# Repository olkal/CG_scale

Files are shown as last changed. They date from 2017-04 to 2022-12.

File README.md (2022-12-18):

# F3X CG_scale
Arduino based Open Source CG scale for F3X gliders (and other model airplanes)
The scale can be used for most modern F3F/F3B gliders with slim fuselages and will calculate the CG and weight.

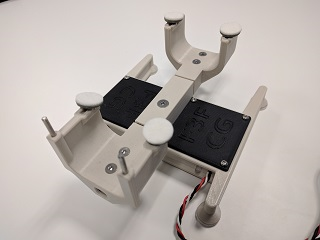
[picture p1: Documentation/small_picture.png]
CG_scale


Update 18.12.2022 1.2.2, changed to a better i2c library for the 1602 LCD

Update 05.02.2022 1.2.1, minor bug fix + optional larger LCD box bottom part

Update 01.12.2021 1.2.0, Arduino code re-write:
- New function: Serial Monitor menu/input
- New function: Calibration routine for loadcells
- New function: Calibration routine for battery voltage
- Configuration parameters in new file config.h
- Store calibration values in EEPROM
- I2C Display code changed
- Display battery voltage also for I2C display
- Optional Zero Offset button included
- Low battery warning
- Updated instructions, circuit diagram and BOM
- ++

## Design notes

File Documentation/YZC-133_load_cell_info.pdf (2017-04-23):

15V DC YZC-133 2kg Weighing Sensor Load Cell Aluminum Alloy Electronic Scale Weighing Sensor
Rated Load: 2Kg
Rated Output: 1.0 ±0.15mV/V
Zero Output: ±0.1mV/V
Cree: 0.03%F.S./30min
Input End: Red+, Black-Output End: Green+, White-Input Impedance: 1115±10% Ω Output Impedance: 1000±10% Ω
Maximum working voltage: 15V DC
Operating temperature range: -20~60°C
Total Size: 80 x 13 x 13mm/3.14 x 0.51 x 0.51"(L X W X H) Material: Aluminum Alloy
Weight: 23g

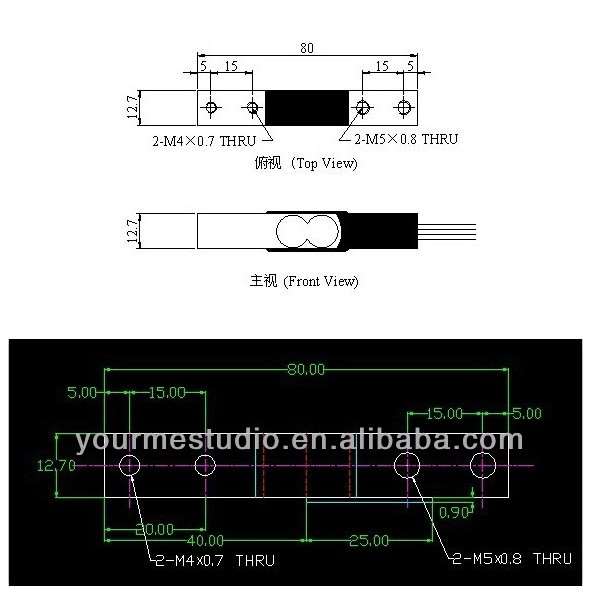
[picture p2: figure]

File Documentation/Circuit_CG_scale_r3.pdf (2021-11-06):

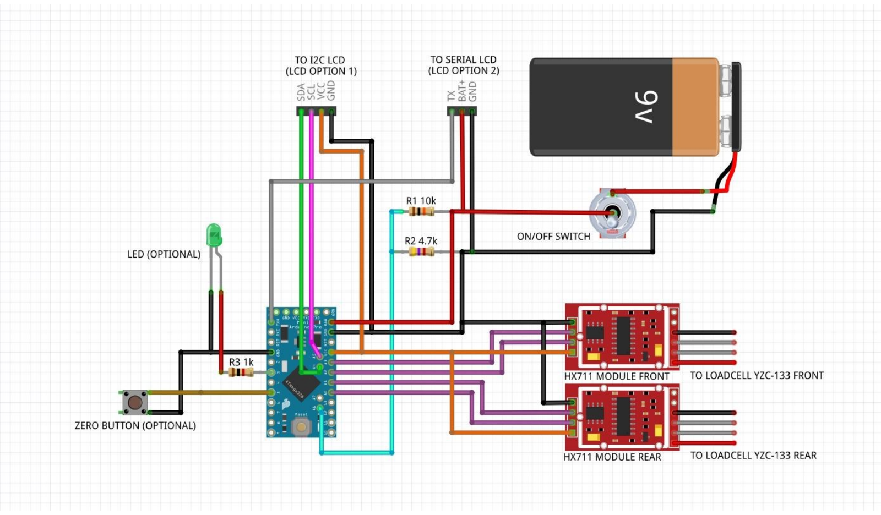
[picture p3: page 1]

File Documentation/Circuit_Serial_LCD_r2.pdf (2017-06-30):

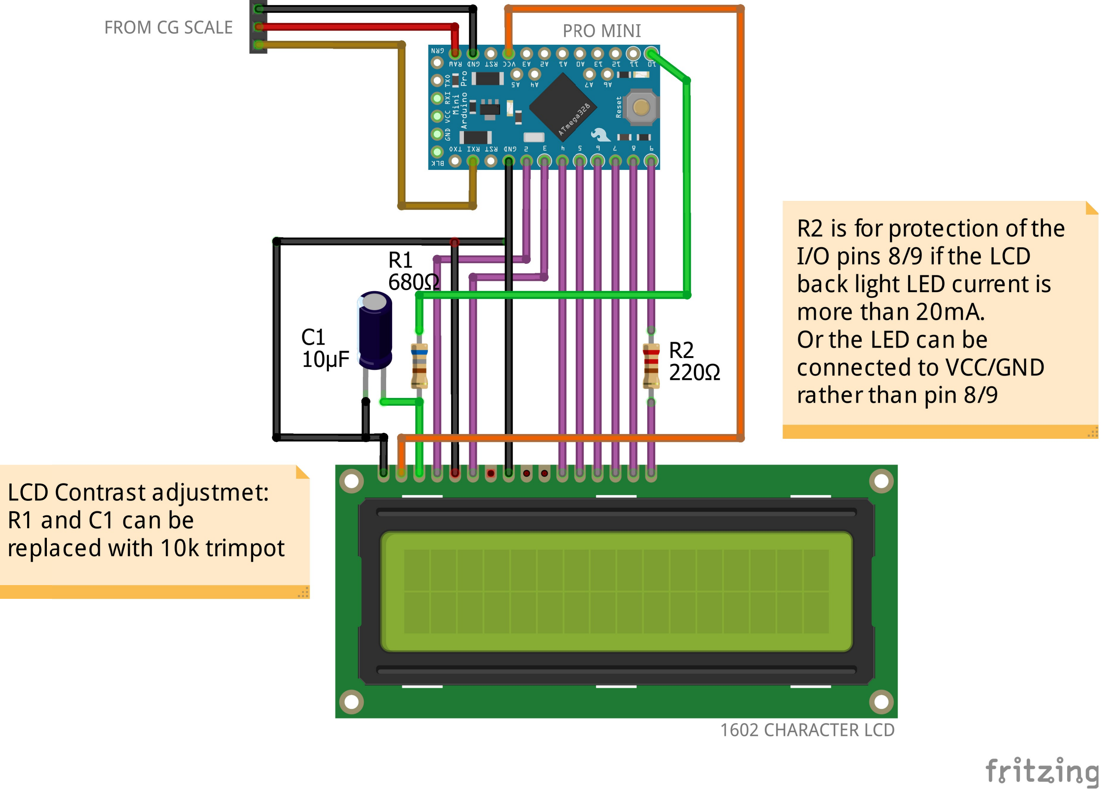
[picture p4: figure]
LCD Contrast adjustmet: R1 and C1 can be replaced with 10k trimpot

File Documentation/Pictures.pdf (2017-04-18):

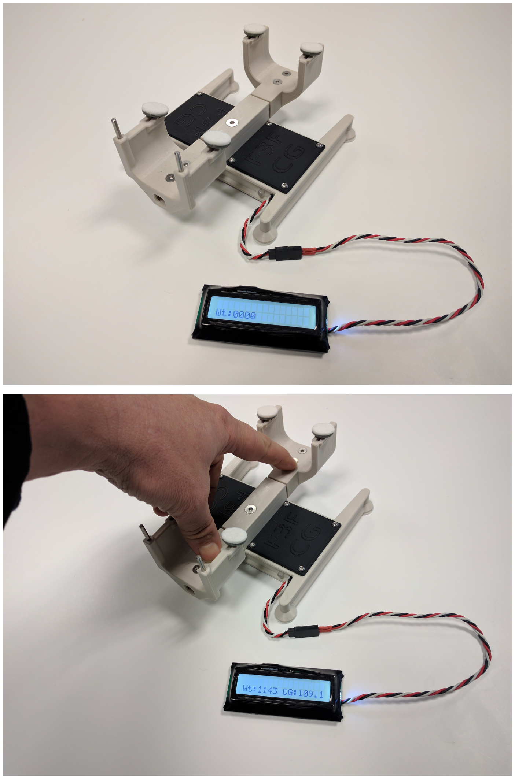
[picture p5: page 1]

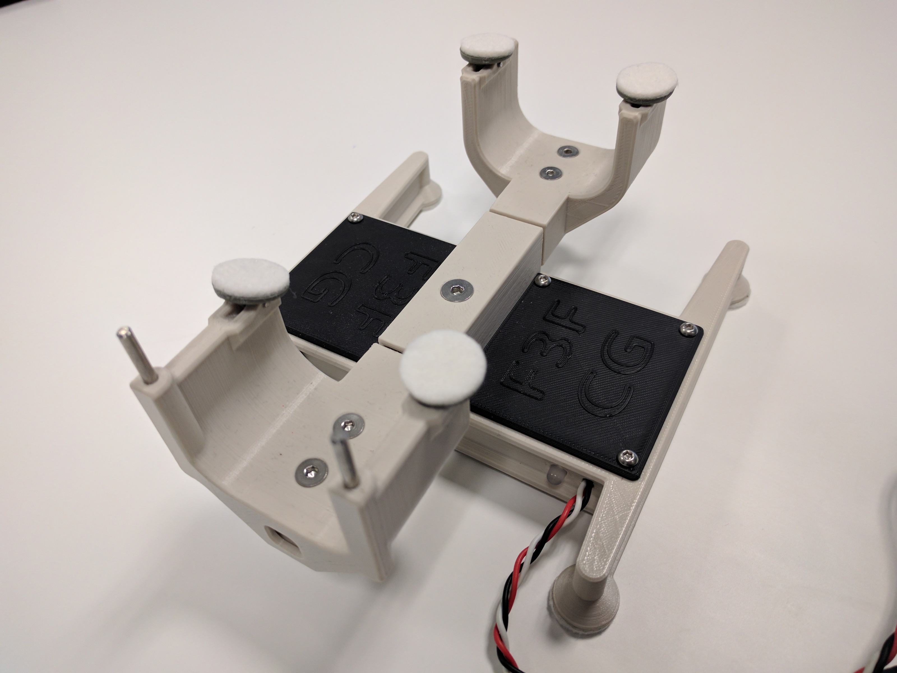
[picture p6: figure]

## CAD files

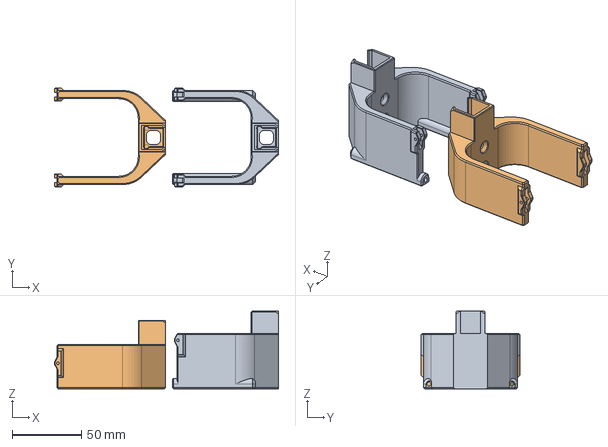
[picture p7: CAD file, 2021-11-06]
Documentation/Source files/CG_scale_parts_f5j_3dprint.stp
161.8 x 71.4 x 56.0 mm

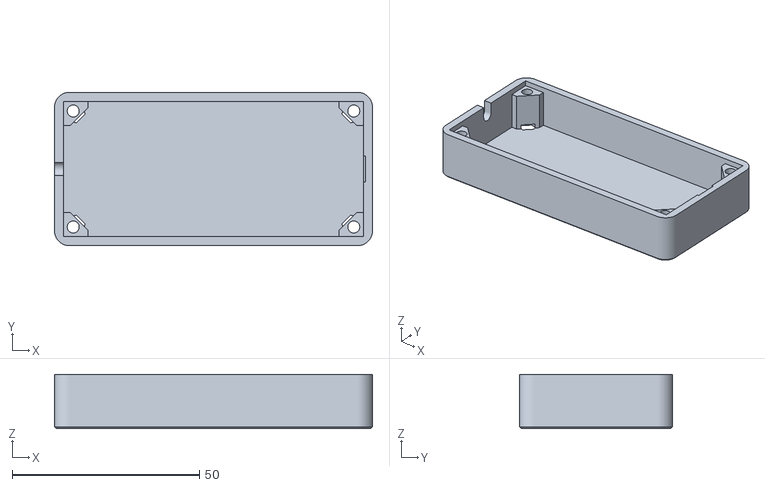
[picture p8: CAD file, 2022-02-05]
STL print files/LCD_case_bot_2.stl
85.0 x 41.0 x 14.5

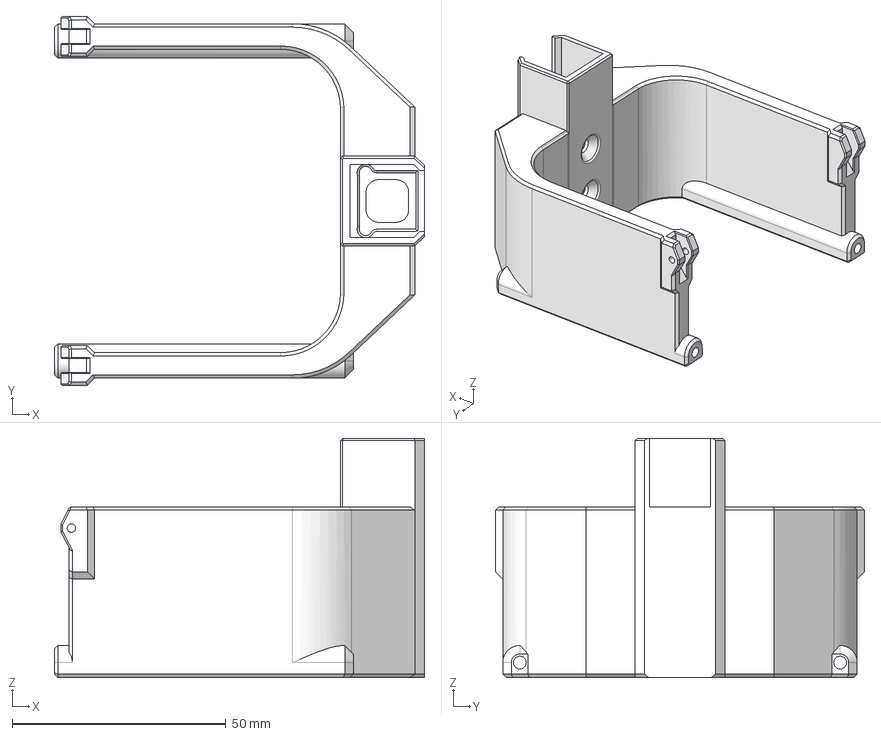
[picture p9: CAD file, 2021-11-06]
Documentation/Source files/CG_scale_front_support_big-version.step
86.7 x 86.4 x 56.0 mm

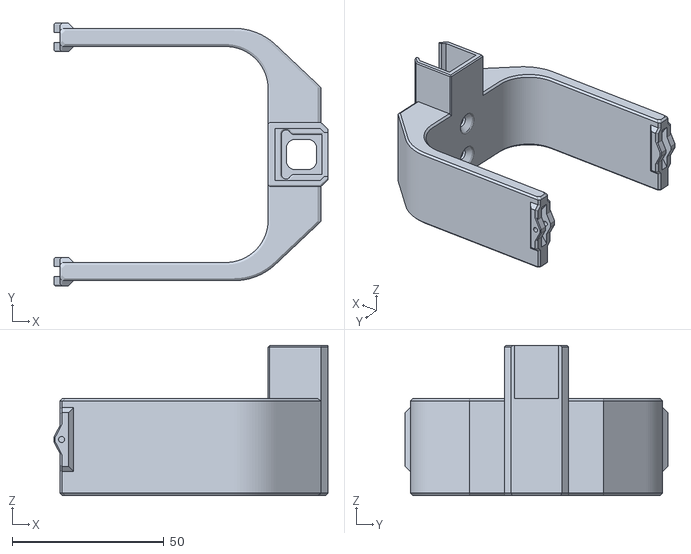
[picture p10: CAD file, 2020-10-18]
STL print files/CG_scale_rear_support_big-version.stl
90.2 x 86.5 x 49.5

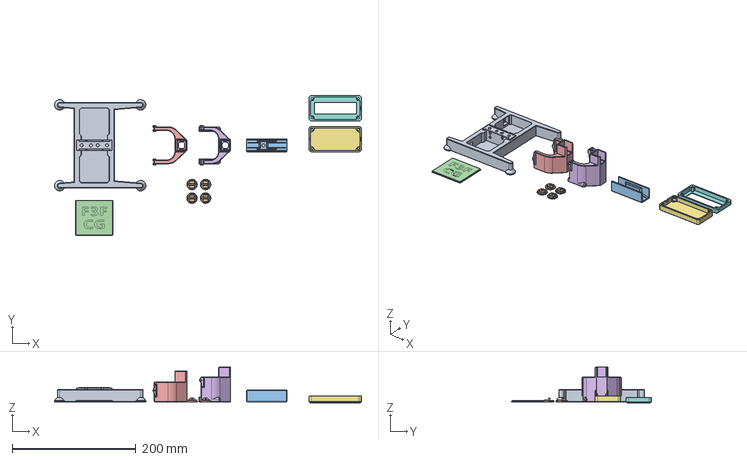
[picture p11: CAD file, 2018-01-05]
Documentation/Source files/CG_scale_parts_3dprint.stp
497.1 x 226.5 x 57.6 mm

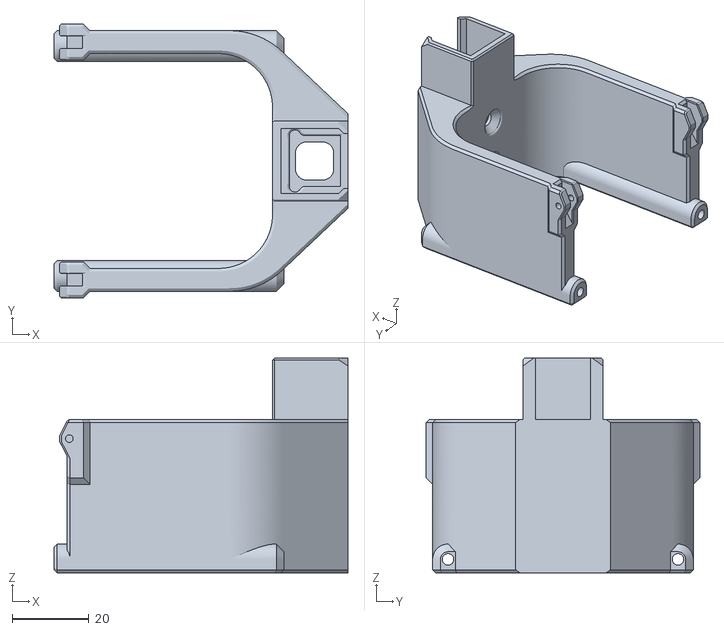
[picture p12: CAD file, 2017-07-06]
STL print files/CG_scale_front_support_f5j-version.stl
76.7 x 71.4 x 56.0

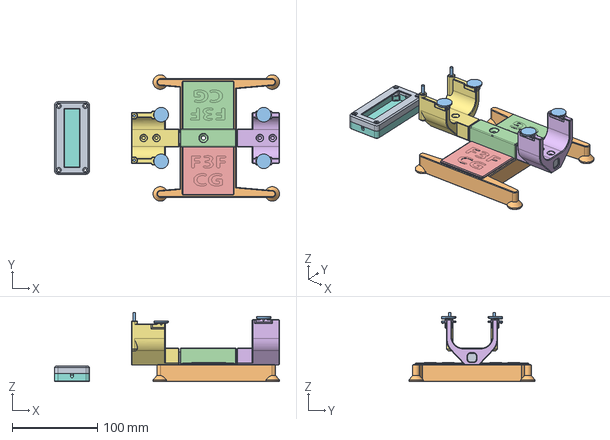
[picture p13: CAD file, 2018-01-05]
Documentation/Source files/CG_scale_assmbl.step
263.3 x 147.9 x 81.1 mm

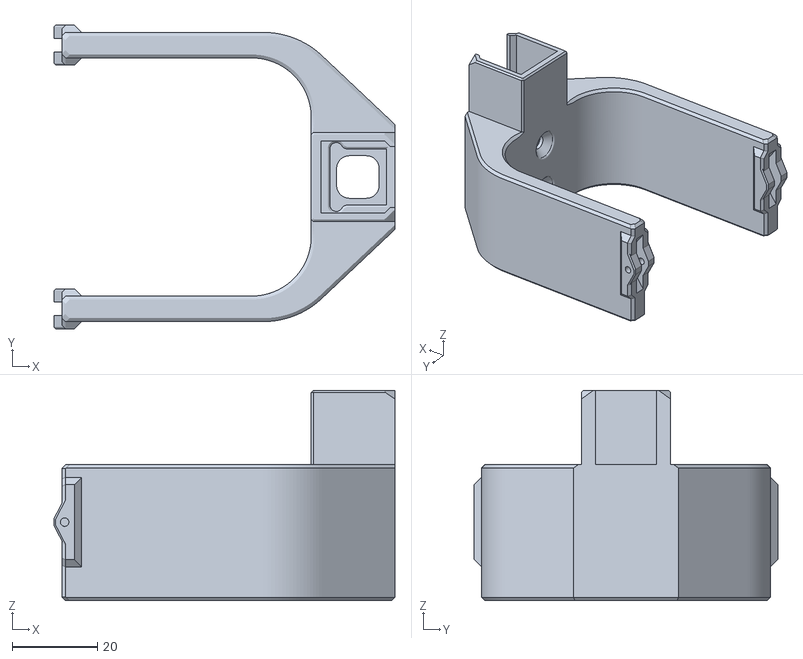
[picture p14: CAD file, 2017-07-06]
STL print files/CG_scale_rear_support_f5j-version.stl
80.2 x 71.4 x 49.5

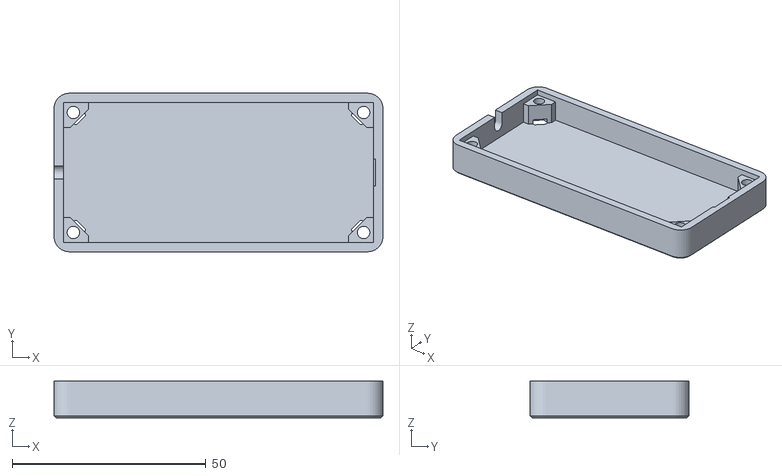
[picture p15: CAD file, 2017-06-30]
STL print files/LCD_case_bot.stl
85.0 x 41.0 x 9.50

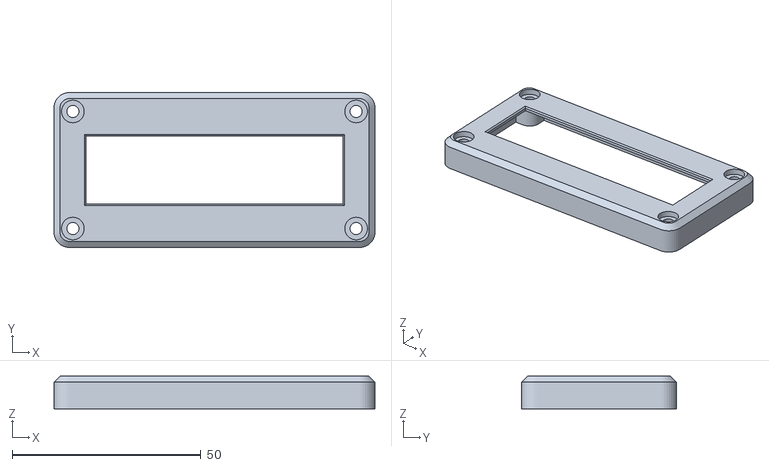
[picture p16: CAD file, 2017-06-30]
STL print files/LCD_case_top.stl
85.0 x 41.0 x 8.70

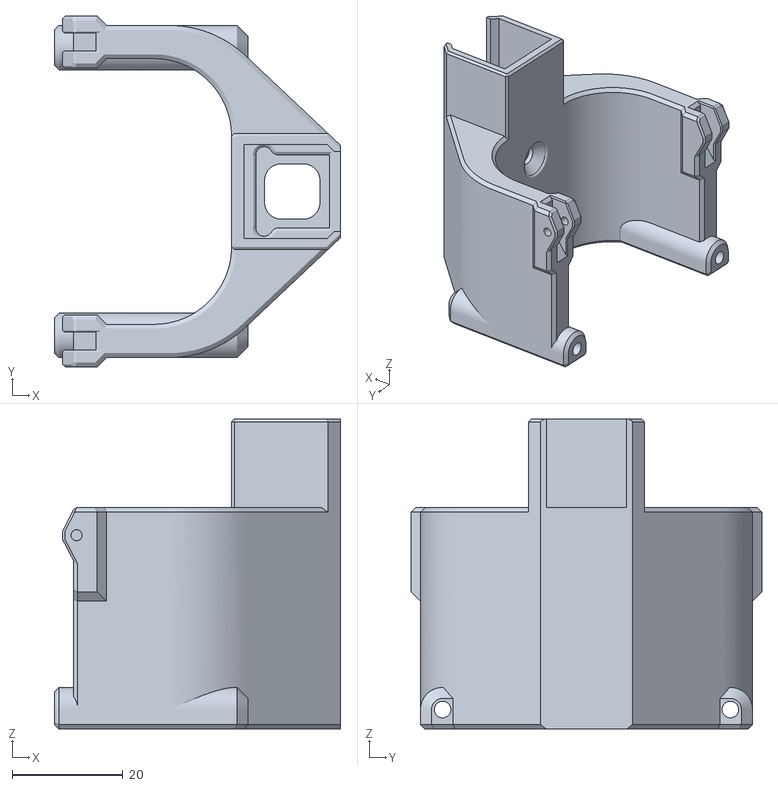
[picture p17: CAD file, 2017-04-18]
STL print files/CG_scale_front_support.stl
51.7 x 63.4 x 56.0

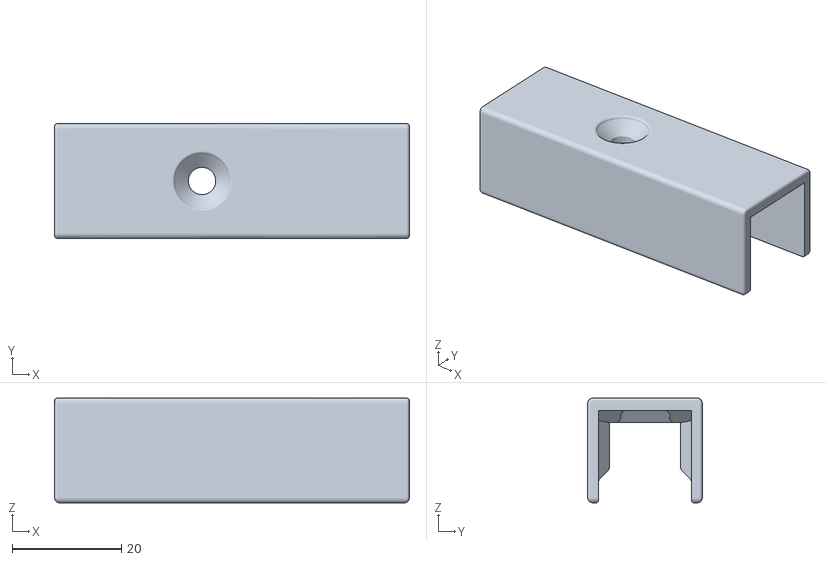
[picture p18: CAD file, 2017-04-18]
STL print files/CG_scale_loadcell_cover.stl
65.0 x 21.0 x 19.2

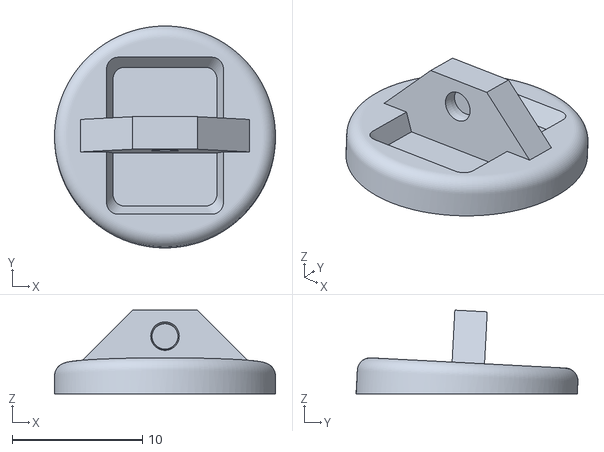
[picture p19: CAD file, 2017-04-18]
STL print files/CG_scale_wing_pad.stl
17.0 x 17.1 x 6.44

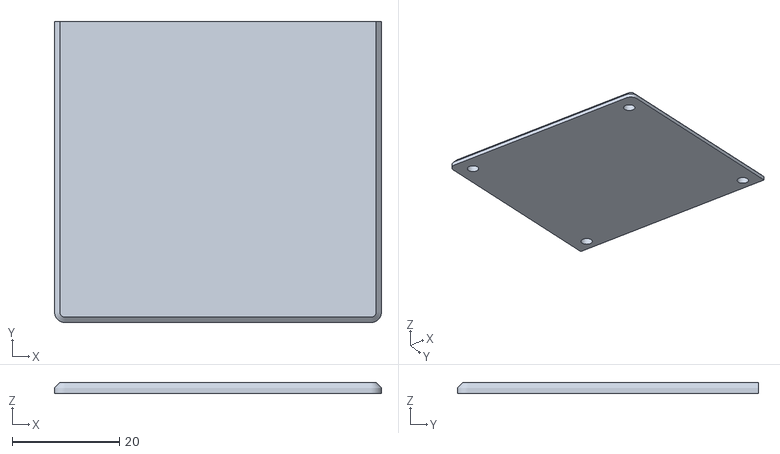
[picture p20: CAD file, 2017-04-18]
STL print files/CG_scale_framecover.stl
61.0 x 56.2 x 2.00

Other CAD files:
Documentation/Source files/CG_scale_rear_support_big-version.step
STL print files/CG_scale_front_support_big-version.stl
STL print files/CG_scale_rear_support.stl
STL print files/CG_scale_framecover_f3f.stl
STL print files/CG_scale_frame.stl

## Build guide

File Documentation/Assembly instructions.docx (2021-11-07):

# Guide to assembly of the Arduino based

# CG Scale for F3X gliders

# (and other model airplanes) by Olav Kallhovd

This scale can be used for most modern F3F/F3B gliders with slim fuselages using the standard supports. If you have chosen to print the _big versions of the supports, you will also be able to fit many other models on the scale.

The maximum load is ~5kg.

This guide assumes that you are already familiar with loading software onto an Arduino, and that you have already done this, or at least will do it before using the scale.

## Drilling and fitting:

Before you get into soldering, you need to prepare the printed parts.

Any penetrating holes are blinded for better print quality. These have to be drilled through before assembly.

Depending on the dimensional accuracy of your 3D printer, some of the holes, including the ones to fit the nuts, may be slightly undersized. Carefully use a suitable drill-bit to enlarge the holes.

For the deep holes on the underside of the base that hold the load cell screws to the base, be careful to not drill too deep.

The load cell cover that conceals the gap in the center of the scale, likely needs some sanding on the inside to prevent it from rubbing on the wires from the load cells. This will become clear when fitting it over the load cells.

## Assembly, mechanical parts:

1. Install M3 nuts in the frame. If the holes for the nuts are too small, gently push the nuts into the holes with a hot soldering iron, and they should slide right in.
2. Attach the load cells with the text on the ends pointing outwards and right side up. The 2kg cell goes in front and the 3kg at the back. The load cell contact surfaces must be flat and true, and may need some work with a small file, or you may have to carefully remove some of the silicone.

Be VERY careful that you don’t damage the wires under the silicone.

3. Check overall alignment. Everything must be straight and true for the scale to be accurate. Use a file on the plastic parts if any adjustment is required.
4. Thread the wires from the rear load cell through the small hole under the cells so they are available on the side where you will be fitting the electronics.
5. Fit the small wing pads to the supports. The 4 wing pads are angled for wing dihedral and must be installed with correct orientation, sloping inwards slightly. For a hinge, use some thin steel pushrod. The hinges for the wing pads must be loose to avoid any binding and to give some allowance for different wing dihedrals. Use a 2mm drill bit on the hole in the wing pads if they are too tight. Secure the rods in place with a tiny dab of CA on the outside of the hole in the support and fit a small piece of soft foam or felt to each pad. Using soft material with low-friction may reduce internal binding between the pads, hence improve accuracy.
6. Scuff the ends of some 3mm steel pushrod or pianowire using coarse sandpaper or a dremel, and glue into the holes on the front support using epoxy or CA. The rods must have a tight fit so they are perfectly vertical and aligned. Ensure that they protrude enough to allow for wing profiles with a high LE.
7. Use callipers to take some accurate “As-built” measurements of the assembled unit. The dimensions “WingPegDist” and “LEstopperDist” must be included in the Arduino sketch. See figure 1 below.

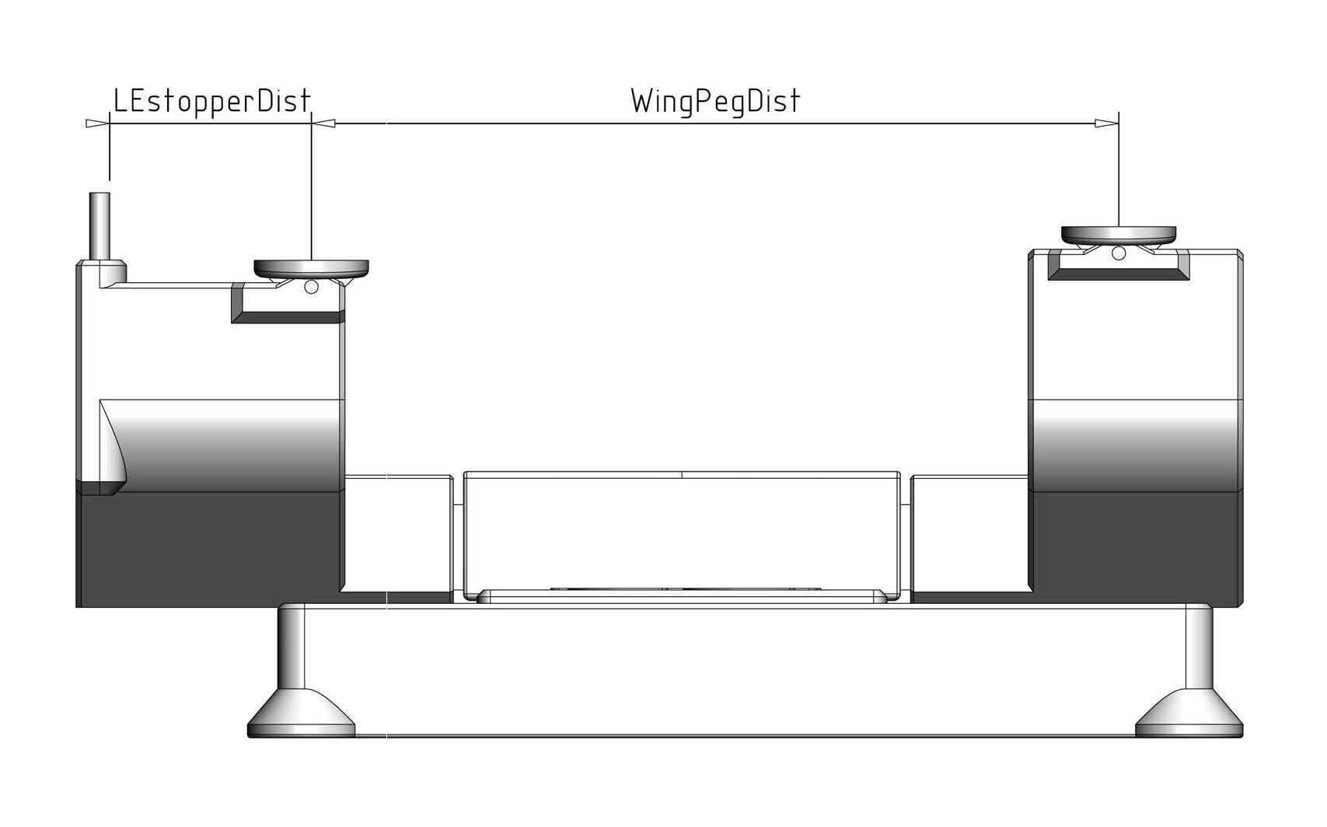
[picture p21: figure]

Figure 1

## Assembly, electronics:

1. Solder each of the load cells to a HX711 module. Be aware that the colours of the wires in the diagram may be different from the cells you have purchased.

To avoid shorting something within the compartment, it’s a good idea to carefully wrap the modules in heat shrink or kapton tape after soldering.

2. Solder the remaining components according to the diagram. Take note of any wires that need to be threaded through a hole before soldering them. This includes wires for the switch, battery and display.
3. I2C Display:

If you are using an LCD display with I2C backpack, ignore the LCD diagram “Circuit_Serial_LCD” and instead:

- Connect Display GND to any Arduino-GND that is free
- Connect Display VCC to Arduino VCC
- Connect Display SDA to Arduino A4
- Connect Display SCL to Arduino A5
4. Serial Display:

If you are using an LCD display with an Arduino Mini backpack for serial communication, connect parts according the LCD diagram “Circuit_Serial_LCD” and upload sketch SimpleSerialDisplay.ino to the Arduino Mini.

The Zero-Button and the LED light is optional.

Instead of using a 9V battery as suggested in the diagram, you can choose to fit a JST connector outside the base and use a 2S Lipo battery. Your power source simply needs to supply at least 6V and no more than 12V.

## Software:

If you haven’t already done so, this would be a good time to upload the software. Download and install the Arduino IDE on your PC. Copy the Github CG_scale folder to the Arduino Sketch folder on your PC. If you use an Arduino without USB, like the Arduino Mini you need an USB to TTL programming adapter for interfacing.

Check the configuration settings in the file config.h and do changes if needed. Now, upload the sketch CG_scale.ino onto the Arduino controller.

If you are using a Serial display rather than an I2C display, you must also upload the sketch SimpleSerialDisplay.ino onto the Arduino controller for the display.

## First use/calibrating:

1. Connect USB and open the Arduino IDE Serial Monitor. The “Serial menu” will appear.
2. Connect the battery (the voltage may affect calibration of the loadcells).
3. Now, calibrate loadcell Front, loadcell Rear and battery voltage by following the instructions. When asked to save calibration values to EEPROM, send ‘y’.

## Using the CG Scale:

1. Turn the scale on without any model on the supports.
2. Wait for the initialization to complete before placing a model on it.

This allows for the scale to set itself to 0g.

3. Place the model on the supports.
4. Ensure that the leading edge of the wings are touching the stops on both sides.
5. The display will show the total weight of the model and the Center of Gravity.
6. Using your fingertips under the wing you can lift and reposition the model on the scale a few times to ensure a consistent measurement and that there is no binding forces between the supports.

Additional notes: The model is measured with a slight "nose down" angle. This is intentional and is not adjustable, but it is possible to change the angle by modifying the front or the rear support height. If properly built, the scale is as accurate as you can place the model on it. Try to relocate the model a few times to verify that the measured CG value is repeatable.

Sensitivity: Internal

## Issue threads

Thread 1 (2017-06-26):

Wider supports

natxopedreira, 2017-06-26:
Hello

First thanks for this work, its very nice.

I would like to make a suggestion, maybe you can make the wing supports a bit wider... i printed one set and for example are too narrow for f5j gliders, like xplorer for example

Thanks!

olkal, 2017-06-27:
Hi!
I guess I could do that. However, I wish to keep the design as rigid and
compact as possible. How much wider would it need to be for a typical f5j
model? Does the supports need to be higher as well?

Olav

On 27 Jun 2017 1:19 am, "natxopedreira" <notifications@github.com> wrote:

Hello

First thanks for this work, its very nice.

I would like to make a suggestion, maybe you can make the wing supports a
bit wider... i printed one set and for example are too narrow for f5j
gliders, like xplorer for example

Thanks!

—
You are receiving this because you are subscribed to this thread.
Reply to this email directly, view it on GitHub
<https://github.com/olkal/CG_scale/issues/1>, or mute the thread
<https://github.com/notifications/unsubscribe-auth/ACtPUND3cDCFzH-snxHCtp1t1DHaElfhks5sIDyWgaJpZM4OF-AZ>
.

natxopedreira, 2017-06-27:
Hello!

I have an xplorer 3 f5j and my fuse measure a width of 39mm at LE, so not much wider than now, but you are right the worst part its fuse heigh, at LE its 59mm!!. I asked some friends about other models size (kappa, pike,...) but i will think will be very similar, i can tell you the amount of width/height that will be need to implement in my opinion or tell you other f5j fuse sizes, what you prefer.

I dont know 3d modeling, if not i not bother you and i will redo the supports myself....

As software/hardware im taking another route, im building mine on a esp866 with an http server in ap mode so i will not use an lcd, instead i will see the data on my mobile.

Thanks!

olkal, 2017-06-27:
Okay, 59mm sure is a lot higher than the original design. Can you measure the fuselage hight 30mm behind the LE?

natxopedreira, 2017-06-27:
50mm from bottom to "wing base" at 30mm from LE

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

olkal, 2017-06-28:
Thanks, I will look into it.

olkal, 2017-06-29:
In the attached files the support height has been increased with 25mm and the width with 8mm. Please let me know how it works and how much clearance you get with these.

[CG_scale_supports_f5j.zip](https://github.com/olkal/CG_scale/files/1111681/CG_scale_supports_f5j.zip)

natxopedreira, 2017-06-29:
Thanks!!, tomorrow i will print those and test

natxopedreira, 2017-07-01:
I print the new supports and fit ok. In height +-9mm of clearance and in width +-3mm from each side to wing pads

Thanks for changing the files to fit f5j gliders!!!

Closed 2017-07-01.

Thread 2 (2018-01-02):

CAD Source-files, to be able to adapt to own needs

Nebukadneza, 2018-01-02:
Hi Olav,

thanks for your great work on this project … I’m just ordering all the parts to print and build one or two of these beauties.

One thing i was wondering about is whether it would be possible to release the CAD Source-files? This would make it possible for me and other enthusiasts to adapt the scale to specific needs, especially regarding fuselage proportions, but also possibly making the construction sturdier for heavier uses.

Even if the CAD you used to construct these does not allow great interchangeability, some lossy but portable format (STEP? Is there something better out there?) would help a lot.

I think this would greatly help many users, and widen the adoption of this great “thing” even more.

Thanks for your work, I’m looking forward to building …
Best,
-Dario

olkal, 2018-01-05:
Hello Dario!

Thanks for the kind words!
You are not the first to ask me for the source file. The original design is
made in Microstation and I am a bit concerned of licensing issues as the
software is licensed to my employer. I don't think the original .dgn file
is easily imported to other software anyway.
But I have included a universal step file at the respository now, I hope
you (and others) can use that.

Olav

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

--
Med vennlig hilsen
Olav Kallhovd

Nebukadneza, 2018-01-05:
Hi Olav,

thanks for adding the files. This is indeed incredibly helpful!

Thanks a Bunch, and Best Regards from (rainy) Germany …
-Dario

Closed 2018-01-05.

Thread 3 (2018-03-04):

Fritzing and Documentation Source

Nebukadneza, 2018-03-04:
Hi,

I have now built 3 scales after your model. Wow, everything works so smoothly ^_^. Thanks a bunch!

To ease building, I quickly switched to using these ready-made LCDs which come with a I²C-Port-Expander piggybacked. Much less soldering, no custom circuit, and no 2nd Arduino to program!

I added optional support for this „third“ display-type (after serial and serial-to-arduino), and would like to PR this. However, I’d like to add documentation and wiring information for future users too.

So, what do you say about switching the documentation to an editable format, like MarkDown? Also, could you maybe share the source-fritzing for your wiring-schematic? That way my wiring-schematic would look the same as yours, which is nicer for users.

Let me know what you think … ^_^.
Thanks
-Dario

olkal, 2018-03-05:
Hi Dario,
Yes, please send me an email (I added one to my profile), and we can work something out.

Olav

Stwilkie, 2018-03-27:
I am about to make a few of these, is there any eta on the addition for the new display type ? & Thanks

Nebukadneza, 2018-04-02:
Hi,

I added some plaintext documentation and PRed as #5 .

Hope this helps! ^_^
-Dario

skythj, 2019-02-23:
Hello, thank you for sharing. I would like to ask you this question.

How to connect "TO LCD" and "FROM CG SCALE" in the two wiring diagrams? Thank you.

Tripel334, 2020-10-09:
> Hello, thank you for sharing. I would like to ask you this question.
>
> How to connect "TO LCD" and "FROM CG SCALE" in the two wiring diagrams? Thank you.

See readme for I2C in documentation. A4 pin on the arduino connects to SDA on the I2C and A5 to SCL. VCC and GND to available VCC and GND on the arduino.

olkal, 2021-12-08:
New wiring diagram in release 1.2.0

Closed 2021-12-08.

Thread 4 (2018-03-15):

New front rear supports

Hangrocka, 2018-03-15:
hey guys,

can anyone design and release a .stl file of a bigger support for example like already existing, ....ky design, with a width of 86 mm and height of 79mm?

thanks and br,
mat

Stwilkie, 2018-03-22:
I should be able to knock you up a model for wider sizes, will have a look at it over the weekend.

Hangrocka, 2018-03-22:
Fine, looking forward to it, thank you.

Stwilkie, 2018-03-23:
Hey Hangrocka, i have the bigger arms ready for you but not sure what the protocol is, do i upload them somewhere or do you have an email address i can send them to ?

Hangrocka, 2018-03-24:
hi, you can send it to       mo_s@mail.de
thanks and best regards

Nebukadneza, 2018-04-02:
Hi,

I’d say the best would be to open a pull-request for adding these files. I’m also interested by the way — and thanks ^_^.
-Dario

Closed 2018-04-03.

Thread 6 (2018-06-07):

BOM lists a 2kg and 3kg sensor but only 3kg sensor is supported by 3D parts

JM-DfT, 2018-06-07:
It is mentioned that  2 kg and 3kg sensor are supported but the 3D printed parts only support 3kg sensors (drill holes for 2kg and 3kg sensors do not match),

JM-DfT, 2018-06-08:
Related to the above: current BOM suggests 20mm M5 screws, but IMHO at least 25mm screw length is needed (13mm for the loadcell, 8mm for the screw hole + 5mm for the bolt). An alternative is to screw the 2 loadcells from the bottom of the centre piece, but this requires adjustment of the screw holes in the 3D print.

JM-DfT, 2018-06-08:
Addendum to last post: 20mm hex socket with circular (8.5 mm) head fits from the bottom

olkal, 2018-06-10:
Hi
The YZC-133 load cells are availabale in at least 1kg,2kg,3kg and 5kg versions. They should all have exactly the same dimensions, as shown here: https://github.com/olkal/CG_scale/blob/master/Documentation/YZC-133_load_cell_info.pdf . If the dimensions is different, I suspect that the seller has sendt you a different load cell model.

As for the screws listed in the BOM, they should fit, but the head diameter must be max 9mm.  Countersunk M5*20 screws inserted from the bottom of the frame will go aprox. 6.5mm into the M5 threaded holes in the load cell. (the screw is not supposed to go all the way through the load cell). I will see if its possible to increase the hole diameter a bit on next update.

Olav

JM-DfT, 2018-06-12:
Origin of the 2kg and 3kg load sensors provided by my supplier in the Netherlands
(www.opencircuits.nl) is indeed unclear - external dimensions of the sensors were exactly the same but the mounting holes are differently spaced (10 mm vs. 15mm). Point of attention for other users when ordering load sensors.

Regarding the screws: flat head screws are fine for mounting the F3J/F5J support (from the top) but not for mounting the central support (head of the screw is too high and prevents placing the cover). I used  4 screws from the bottom for the central part and this works just fine.
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

Closed 2018-06-12.

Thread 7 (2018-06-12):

HX711

Grifnz, 2018-06-12:
Hi, Re your comment on the quality of some HX711 modules.  I can see several on AliExpress, but cant see how to pick the units with 10uf capacitors.  Can you link me to a good unit please?

olkal, 2018-06-12:
[This](https://www.aliexpress.com/item/1PCS-HX711-Dual-channel-24-bit-A-D-Conversion-Weighing-Sensor-Module-with-Metal-Shied/32804731758.html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,searchweb201602_5_10152_10151_10065_10344_10068_5722815_10342_10343_10340_5722915_10341_5722615_10696_10084_10083_10618_10307_5722715_10059_100031_10103_10624_10623_10622_5722515_10621_10620,searchweb201603_25,ppcSwitch_5&algo_expid=aa0d78ef-2485-41ef-ac3c-3fae05c802be-3&algo_pvid=aa0d78ef-2485-41ef-ac3c-3fae05c802be&transAbTest=ae803_1&priceBeautifyAB=0) module is okay.

aloyz, 2020-11-16:
in the .ino code comment line 8 : XH711 stated as "128 bit resolution" ADC. datasheet describes the chip as 24bit resolution and selectable 32, 64 or 128 gain. confused me for a sec :)

Closed 2018-06-16.

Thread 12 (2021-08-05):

Where must I connect R1 & R2

Duhaubois, 2021-08-05:
Hello,  I don't know where I must connect R1 & R2 : On the "Circuit_CG_scale_r2" file, they are welded on the "A4 pin" of the Arduino. But on your picture we can see they are welded on the "A3 pin".
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

olkal, 2021-08-06:
Hi!
R1 and R2 (battery voltage measurement) can be connected to any pin from A0 to A7. If you don't use A4 you must correct the code in line 37 `byte batRefPin = A4;`

Closed 2021-08-23.

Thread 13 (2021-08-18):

Check for output to I2C is "odd"

haumovie, 2021-08-18:
Thanks for a great project with some really nice and comprehensive documentation.
A couple of points:
Calibration is described as needing to be written to EEPROM, but it seems unclear exactly how and why. The values look to be used when the code is run and nothing seems to be necessary to un- and  re-comment. I'm guessing the code has changed but the instructions didn't?

I'm quite certain that there's a bug in the check for the output value to I2C.
`#ifdef I2CDISP
  if (output != 0)
    Serial.println("You have I2CDISP defined, but output is not 2. Are you sure thats right?");`

But surely, the message should be displayed on serial if the value is different from 2 rather than different from 0?

olkal, 2021-08-23:
Hi!
Sorry for delayed reply!
Yes, it should probably be `#ifdef I2CDISP if (output != 2)` in line 84. The I2C display code was added by someone else and I guess I never checked it properly.

Regarding calibration and EEPROM; my HX711_ADC library have the option for saving the calibration value to EEPROM, but this has not been implemented in the CG scale code. However, If you want to use EEPROM you should be able to figure it out by playing with the HX711_ADC library example files.

The CG scale example code defenently needs a major clean-up to add some features and some bug-fix. I don't have time for it at the moment, but it will be on my to-do-soon list.

olkal, 2021-12-08:
Fixed in release 1.2.0

Closed 2021-12-08.

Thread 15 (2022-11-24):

No LCD output, no load cell data

swampd32618, 2022-11-24:
I've built this according to assembly instructions but get no output on the LCD and get no reading of the load cells. The display works with the examples in the LiquidCrystial_I2C library and I entered the correct I2C address in the config.h file. But all I get is a row of dark rectangles on the first line of the display.

Also, when I run the sketch and open the Arduino IDE serial monitor I can successfully run the menu, but get no valid data from the load cells. Once again, running the examples from the HX711_ADC-master library gives good data, so the connections are correct.

Any suggestions? Thanks in advance!

olkal, 2022-11-25:
Hi!
See if you can find anything in config.h file that is different from the working example files you tried, for example the HX711 pin designations in line 58-61.

swampd32618, 2022-11-27:
Got it working. Battery voltage reading is off even after calibration, but I'll work on that. Thanks for your help.

olkal, 2022-11-28:
Great!

Closed 2022-11-28.

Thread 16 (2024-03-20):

Help/Clarification

africanman1961, 2024-03-20:
Hello olkal
Thank you for this project. Please note, I am a beginner.
My question is to do with the wiring of the lcd, specifically I2C, Circuit_CG_scale_r3.fzz refers. you have a wire running from 16 on the arduino to the positive and negative battery terminals. Please could you tell me what this is for and if it is necessary for connecting to an I2C LED.

Thank you
Mark

olkal, 2024-03-21:
Do you mean the connection from Arduino pin A6? If so, that is for measuring the battery voltage. If you don't want to show the battery voltage on the LCD you can omit the wiring to pin A6 and comment out the line 76 in file CG_scale.ino: `displayVoltage();`

africanman1961, 2024-03-27:
Hello Olkal
Thank you very much for answering my question. I understand your explanation. I would like to include the battery voltage display on my scale.

Talking about this same wire to pin A6, I note on the schematic a 10k resistor coming off the positive battery wire and a 4.7k resistor coming off the negative battery wire. Both connect into the wire going to the A6 pin. Forgive me, but will this not cause a short circuit?

Thank you
Mark

olkal, 2024-03-27:
Hi!
No, the 2 resistors tied to + and - is called a "Voltage divider" and it will reduce the voltage to input pin A6 from your 9V battery, this is required as voltages >5V can blow the MCU input pin.

africanman1961, 2024-03-27:
Hi Olkal
Thank you very much for your reply. I am learning new things with this project.

Appreciate your help.
Mark

africanman1961, 2024-04-14:
Hi Olkal

Please could you help, I would like to move the weight display to the top line and add one decimal place. Please indicate how I could do this in the sketch.

As always, appreciate your help,
Mark

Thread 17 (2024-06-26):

Inquiry about using load cells in Argentina

drsistemas01, 2024-06-26:
Good morning,

I'm having difficulty finding the YZC-133 3kg load cell in Argentina. However, I have found 2kg load cells available.

My question is: Can I use two 2kg load cells instead of one 3kg load cell? If so, would I need to make any modifications to the code?

Thank you for your attention and I look forward to your response.

Best regards.

olkal, 2024-06-26:
Hi!
You can replace the suggested 3kg load cell in front with a 2kg load cell, no modification to the code is required. I guess this will be okay for a model weight of up to about 3-3.5kg, but it depends on how far back your model's CG is.

drsistemas01, 2024-06-26:
Hi!

Thank you very much for the quick response. In Argentina, I can get 2kg and 5kg load cells. What would you advise?

Best regards.

drsistemas01, 2024-06-26:
Hello,

Thank you very much for your prompt response. In Argentina, I can get 2kg or 5kg load cells (5kg ones are easier to find). Which would be the better option? Would I lose accuracy if I use two 5kg load cells instead of two 2kg ones? These will be used for F5J models.

Please excuse my lack of knowledge on this matter, and I appreciate your guidance.
Atte. jose

olkal, 2024-06-26:
In theory the the 2kg cells will provide better accuracy as long you stay within their specified load range, but in reality I don't think there will be any significant difference. So I suggest that you go for the 5kg cells if they are easier to source, they should work fine.

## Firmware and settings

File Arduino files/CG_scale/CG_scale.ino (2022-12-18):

/*
   CG scale for F3F & F3B models
   Olav Kallhovd, 2016-2021
*/
#define VERSION "CG Scale SW v1.2.2"

#include "config.h"
#if defined USE_EEPROM
#if defined(ESP8266) || defined(AVR)
#include <EEPROM.h>
#endif
#else
#undef USE_EEPROM
#endif

//** eeprom address:
#define ADR_LDCELL1_CAL     0
#define ADR_LDCELL2_CAL     4
#define ADR_BATVOLT_CAL     8
#define ADR_LDCELL1_IS_CAL  12
#define ADR_LDCELL2_IS_CAL  13
#define ADR_BATVOLT_IS_CAL  14

#define IS_CAL_VAL          254

//** HX711 library:
#include <HX711_ADC.h> //https://github.com/olkal/HX711_ADC library can be installed from the library manager

//** HX711 constructors:
HX711_ADC LoadCell_1(LoadCell_1_DOUT_pin, LoadCell_1_SCK_pin);
HX711_ADC LoadCell_2(LoadCell_2_DOUT_pin, LoadCell_2_SCK_pin);

#define LCD_LEN 16

//** i2c LCD librarys and declaration:
#ifdef USE_I2CDISP
#include <Wire.h>
#include <hd44780.h> //https://github.com/duinoWitchery/hd44780 library can be installed from the library manager
#include <hd44780ioClass/hd44780_I2Cexp.h> 
hd44780_I2Cexp lcdI2C(I2CDISP_ADR,16,2); // declare lcd object 
#endif

byte seroutput = 0; //0: Serial LCD display, 1: Wt+CG+loadcell value, 2: other (calibration etc.)


//***
void setup() {
  Serial.begin(9600); //don't change if you use the serial LCD display option
  printMenu();
  setupLCD();
  setupLoadcells();

#ifdef USE_ZERO_BUTTON
  pinMode(zero_button_pin, INPUT_PULLUP); //optional led
#endif

#ifdef USE_LED
  pinMode(led_pin, OUTPUT); //optional led
  digitalWrite(led_pin, HIGH);
#endif
}


//***
void loop() {
  //** library function update() should be called at least as often as HX711 sample rate; >10Hz@10SPS, >80Hz@80SPS
  //** longer delay in sketch will reduce effective sample rate (so be careful with use of delay())
  if (LoadCell_1.update() || LoadCell_2.update()) {
    displayWeightAndCG();
  }

  // receive command from serial terminal
  if (Serial.available() > 0) {
    handleIncSerial();
  }

  displayVoltage();
  zeroButton();
  flashLED();
}


//*** set up LCD:
void setupLCD() {
#ifdef USE_I2CDISP
  lcdI2C.begin(16, 2);
  lcdI2C.setBacklight(1);
#endif

  char lcdtext[LCD_LEN + 1] = {"F3X COG scale   "};
  printToLCD(lcdtext, 0);
  char lcdtext2[LCD_LEN + 1] = {"Wait...         "};
  printToLCD(lcdtext2, 1);
}


//*** set up loadcells and calibration values:
void setupLoadcells() {
  long stabilisingtime = 3000; // initial zero/tare precision can be improved by adding a few seconds of stabilising time in startup
  LoadCell_1.begin();
  LoadCell_2.begin();
  byte loadcell_1_rdy = 0;
  byte loadcell_2_rdy = 0;
  while ((loadcell_1_rdy + loadcell_2_rdy) < 2) { //run startup, stabilisation and tare, both modules simultaneously
    if (!loadcell_1_rdy) loadcell_1_rdy = LoadCell_1.startMultiple(stabilisingtime);
    if (!loadcell_2_rdy) loadcell_2_rdy = LoadCell_2.startMultiple(stabilisingtime);
  }

#ifdef USE_EEPROM
  if (EEPROM.read(ADR_LDCELL1_IS_CAL) == IS_CAL_VAL) {
    EEPROM.get(ADR_LDCELL1_CAL, ldcell_1_calfactor);
  }
  if (EEPROM.read(ADR_LDCELL2_IS_CAL) == IS_CAL_VAL) {
    EEPROM.get(ADR_LDCELL2_CAL, ldcell_2_calfactor);
  }
  if (EEPROM.read(ADR_BATVOLT_IS_CAL) == IS_CAL_VAL) {
    EEPROM.get(ADR_BATVOLT_CAL, batvoltage_calfactor);
  }
#endif

  LoadCell_1.setCalFactor(ldcell_1_calfactor); // set calibration factor
  LoadCell_2.setCalFactor(ldcell_2_calfactor); // set calibration factor
}


//*** analog read and return battery voltage in mV units:
int readBattVoltage() {
  long battvalue = analogRead(batRef_pin); // analog reading
  battvalue *= batvoltage_calfactor;
  return battvalue;
}


//*** calculate model weight and CG and display the values:
void displayWeightAndCG() {
  //** calculate CG and update serial/LCD
  static long t1 = 0;
  const long CGoffset = ((WingPegDist / 2) + LEstopperDist) * 10;
  if (t1 < millis()) {
    t1 = millis() + lcdprintInterval;
    float a = LoadCell_1.getData();
    float b = LoadCell_2.getData();
    long weightAvr[3];
    float CGratio;
    long CG;
    weightAvr[0] = a * 100;
    weightAvr[1] = b * 100;
    long weightTot = weightAvr[0] + weightAvr[1];

    if (weightAvr[0] > 500 && weightAvr[1] > 500) {
      long a = weightAvr[1] / 10;
      long b = weightAvr[0] / 10;
      CGratio = (((a * 10000) / (a + b)));
      CG = ((((WingPegDist) * CGratio) / 1000) - ((WingPegDist * 10) / 2) + CGoffset);
    }
    else {
      CG = 0;
    }

    char lcdtext[LCD_LEN + 1] = "Wt:     CG:     ";
    if (weightTot < 0 && weightTot >= - 100) {
      weightTot = 0;
    }
    if (weightTot < -100) {
      lcdtext[3] = 'e';
      lcdtext[4] = 'r';
      lcdtext[5] = 'r';
      lcdtext[6] = '.';
    }
    else {
      lcdtext[3] = (char)(weightTot / 100000) + 48;
      lcdtext[4] = (char)((weightTot % 100000) / 10000) + 48;
      lcdtext[5] = (char)((weightTot % 10000) / 1000) + 48;
      lcdtext[6] = (char)((weightTot % 1000) / 100) + 48;
    }
    lcdtext[7] = ' ';
    if (CG != 0) {
      lcdtext[11] = (char)(CG / 10000) + 48;
      lcdtext[12] = (char)((CG % 10000) / 1000) + 48;
      lcdtext[13] = (char)((CG % 1000) / 100) + 48;
      lcdtext[14] = '.';
      lcdtext[15] = (char)((CG % 100) / 10) + 48;
    }

    printToLCD(lcdtext, 1);

    //**print values to serial terminal:
    static long t2 = 0;
    if (seroutput == 1) {
      if (t2 < millis()) {
        t2 = millis() + serialprintInterval;

        for (byte a = 0; a < 2; a++) {
          Serial.print(F("LdCell_"));
          Serial.print(a + 1);
          Serial.write(':');
          long i = weightAvr[a];
          if (i < 0) {
            Serial.write('-');
            i = ~weightAvr[a];
          }
          Serial.print(i / 100);
          Serial.write('.');
          if ((i % 100) < 10) {
            Serial.write('0');
          }
          Serial.print(i % 100);
          Serial.print(F("   "));
        }
        Serial.print(F("Wt:"));
        Serial.print((weightAvr[0] + weightAvr[1]) / 100);
        Serial.print(F("   CG:"));
        Serial.print(CG / 100);
        Serial.write('.');
        Serial.println(CG % 100);
      }
    }
  }
}


//*** handle battery voltage and display voltage on LCD:
void displayVoltage() {
  static long t = 0;
  if (millis() > t) {
    int batval = readBattVoltage();
    static int last_batval = -1;
    static bool show_value = false;
    static long lastbatwarn_time = 0;
    bool updatebatwarning = false;

    if (batval < lowBatVal) {
      show_value = !show_value;
      lastbatwarn_time = millis();
      updatebatwarning = true;
    }
    else {
      if (!show_value) updatebatwarning = true;
      show_value = true;
    }

    if ((last_batval != batval) || updatebatwarning) {
      char lcdtext[LCD_LEN + 1];
      memset(lcdtext, 32, sizeof(lcdtext));
      if (show_value) {
        lcdtext[0] = (char)(batval / 1000) + 48;
        lcdtext[1] = '.';
        lcdtext[2] = (char)((batval % 1000) / 100) + 48;
        //lcdtext[3] = (char)((batval % 100) / 10) + 48;
        lcdtext[3] = 'V';
      }
      printToLCD(lcdtext, 0);
      last_batval = batval;
    }
    t = millis() + 750;
  }
}

//*** print char array to LCD:
void printToLCD(char *lcdtext, byte lineno) {
#ifdef USE_SERDISP
  if (seroutput == 0) {
    Serial.write(254);
    Serial.write(128 + (lineno * 64)); //pos line 0, char 0
    for (byte a = 0; a < LCD_LEN; a++) {
      Serial.write(lcdtext[a]);
    }
    Serial.write(';'); //end
  }
#endif

#ifdef USE_I2CDISP
  lcdI2C.setCursor(0, lineno); //pos line 0, char 0
  for (byte a = 0; a < LCD_LEN; a++) {
    lcdI2C.write(lcdtext[a]);
  }
#endif
}


//*** print serial input menu:
void printMenu() {
  Serial.println();
  Serial.println(F(VERSION));
  Serial.println(F("Menu:"));
  Serial.println(F("Send 's' to enable weight/CG output to Serial Monitor"));
  Serial.println(F("Send 'z' to set zero offset"));
  Serial.println(F("Send 'c1' to start FRONT load cell calibration"));
  Serial.println(F("Send 'c2' to start REAR load cell calibration"));
  Serial.println(F("Send 'b' to start battery voltage calibration"));
  Serial.println(F("Send 'm1' to manually set FRONT load cell calibration value"));
  Serial.println(F("Send 'm2' to manually set REAR load cell calibration value"));
}


//*** handle incoming commands from serial monitor:
void handleIncSerial() {
  char buf[3];
  memset(buf, 0, sizeof(buf));
  Serial.readBytes(buf, 2);

  if ((buf[0] & 0xFF) == 'z') {
    setZero(); //set zero
  }
  else if ((buf[0] & 0xFF) == 's') {
    //Serial.println(F("print Wt+CG+Loadcell to Serial"));
    seroutput = 1;
  }
  else if ((buf[0] & 0xFF) == 'c') { //if valid command
    if ((buf[1] & 0xFF) == '1') {
      //Serial.println(F("calibrate1"));
      calibrateLoadcell(1); //calibrate loadcell front
    }
    else if ((buf[1] & 0xFF) == '2') {
      //Serial.println(F("calibrate2"));
      calibrateLoadcell(2); //calibrate loadcell rear
    }
  }
  else if ((buf[0] & 0xFF) == 'm') { //if valid command
    if ((buf[1] & 0xFF) == '1') {
      //Serial.println(F("changeSavedCalFactor1"));
      setLoadcellCalValue(1); //set calibration value for loadcell front manually
    }
    else if ((buf[1] & 0xFF) == '2') {
      //Serial.println(F("changeSavedCalFactor2"));
      setLoadcellCalValue(2); //set calibration value for loadcell rear manually
    }
  }
  else if ((buf[0] & 0xFF) == 'b') { //if valid command
    calibrateBatVoltage();
  }
}


//*** set zero offset, both loadcells simultaneously:
void setZero() {
  char lcdtext[LCD_LEN + 1] = {"Setting Zero... "};
  printToLCD(lcdtext, 1);
  boolean _resume = false;
  boolean zero_1 = false;
  boolean zero_2 = false;
  LoadCell_1.tareNoDelay();
  LoadCell_2.tareNoDelay();
  while (_resume == false) {
    LoadCell_1.update();
    LoadCell_2.update();
    if (LoadCell_1.getTareStatus() == true) zero_1 = true;
    if (LoadCell_2.getTareStatus() == true) zero_2 = true;
    if (zero_1 && zero_2) {
      if (seroutput == 1) {
        Serial.println(F("Set zero offset complete "));
      }
      _resume = true;
    }
  }
}


//*** calibrate loadcell, input '1' is front, '2' is rear:
void calibrateLoadcell(byte loadcellno) {
  if ((loadcellno != 1) && (loadcellno != 2)) return;
  int eepromAdr;
  int eepromAdrIsCalibrated;
  float newCalibrationValue;
  char lcdtext[LCD_LEN + 1] = {"Calibration...  "};
  printToLCD(lcdtext, 1);
  Serial.println(F("***"));
  Serial.print(F("Start calibration loadcell "));
  if (loadcellno == 1) Serial.println(F("FRONT:"));
  else Serial.println(F("REAR:"));
  Serial.println(F("Place the CG scale an a level stable surface."));
  Serial.println(F("Send 'z' from serial monitor to set the zero offset."));

  boolean _resume = false;
  boolean zero_1 = false;
  boolean zero_2 = false;
  while (_resume == false) {
    if (Serial.available() > 0) {
      char inByte = Serial.read();
      if (inByte == 'z') {
        setZero();
        _resume = true;
        printToLCD(lcdtext, 1);
      }
    }
  }

  Serial.print(F("Now, place your known mass on the loadcell "));
  if (loadcellno == 1) Serial.print(F("FRONT, "));
  else Serial.print(F("REAR, "));
  Serial.println(F("then send the weight of this mass (i.e. 500.0) from the serial monitor."));
  float known_mass = 0;
  _resume = false;
  while (_resume == false) {
    LoadCell_1.update();
    LoadCell_2.update();
    if (Serial.available() > 0) {
      known_mass = Serial.parseFloat();
      if (known_mass != 0) {
        Serial.print(F("Known mass is: "));
        Serial.println(known_mass);
        _resume = true;
      }
      else {
        Serial.println(F("Invalid value"));
      }
    }
  }

  if (loadcellno == 1) {
    LoadCell_1.refreshDataSet(); //refresh the dataset to be sure that the known mass is measured correct
    newCalibrationValue = LoadCell_1.getNewCalibration(known_mass); //get the new calibration value
#ifdef USE_EEPROM
    eepromAdr = ADR_LDCELL1_CAL;
    eepromAdrIsCalibrated = ADR_LDCELL1_IS_CAL;
#endif
  }

  if (loadcellno == 2) {
    LoadCell_2.refreshDataSet(); //refresh the dataset to be sure that the known mass is measured correct
    newCalibrationValue = LoadCell_2.getNewCalibration(known_mass); //get the new calibration value
#ifdef USE_EEPROM
    eepromAdr = ADR_LDCELL2_CAL;
    eepromAdrIsCalibrated = ADR_LDCELL2_IS_CAL;
#endif
  }

  Serial.print(F("Calculated calibration value is: "));
  Serial.print(newCalibrationValue);
  Serial.println(F(", use this in your project sketch or save to eeprom."));
  
#ifdef USE_EEPROM
  Serial.print(F("Save this value to EEPROM adress "));
  Serial.print(eepromAdr);
  Serial.println(F("? y/n"));
  _resume = false;
  while (_resume == false) {
    if (Serial.available() > 0) {
      char inByte = Serial.read();
      if (inByte == 'y') {
        EEPROM.put(eepromAdr, newCalibrationValue);
        EEPROM.write(eepromAdrIsCalibrated, IS_CAL_VAL);
#if defined(ESP8266)
        EEPROM.commit();
#endif
        EEPROM.get(eepromAdr, newCalibrationValue);
        Serial.print(F("Value "));
        Serial.print(newCalibrationValue);
        Serial.print(F(" saved to EEPROM address: "));
        Serial.println(eepromAdr);
        _resume = true;
      }
      else if (inByte == 'n') {
        Serial.println(F("Value not saved to EEPROM"));
        _resume = true;
      }
    }
  }
#endif
  Serial.println(F("End calibration"));
  Serial.println(F("***"));
}

//*** enter loadcell calibration manually, input '1' is front, '2' is rear:
void setLoadcellCalValue(byte loadcellno) {
  if ((loadcellno != 1) && (loadcellno != 2)) return;
  int eepromAdr;
  int eepromAdrIsCalibrated;
  float c = 0;
  boolean _resume = false;

  Serial.println(F("***"));
  Serial.print(F("Current value for loadcell "));
  if (loadcellno == 1) {
    c = LoadCell_1.getCalFactor();
    Serial.print(F("FRONT is:"));
#ifdef USE_EEPROM
    eepromAdr = ADR_LDCELL1_CAL;
    eepromAdrIsCalibrated = ADR_LDCELL1_IS_CAL;
#endif
  }
  else {
    c = LoadCell_2.getCalFactor();
    Serial.print(F("REAR is:"));
#ifdef USE_EEPROM
    eepromAdr = ADR_LDCELL2_CAL;
    eepromAdrIsCalibrated = ADR_LDCELL2_IS_CAL;
#endif
  }
  Serial.println(c);
  Serial.println(F("Now, send the new value from serial monitor, i.e. 696.0"));
  while (_resume == false) {
    if (Serial.available() > 0) {
      c = Serial.parseFloat();
      if (c != 0) {
        Serial.print(F("Calibration value is: "));
        Serial.println(c);
        if (loadcellno == 1) LoadCell_1.setCalFactor(c);
        else LoadCell_2.setCalFactor(c);
        _resume = true;
      }
      else {
        Serial.println(F("Invalid value, exit"));
        return;
      }
    }
  }

#ifdef USE_EEPROM
  Serial.print(F("Save this value to EEPROM adress "));
  Serial.print(eepromAdr);
  Serial.println(F("? y/n"));
  _resume = false;
  while (_resume == false) {
    if (Serial.available() > 0) {
      char inByte = Serial.read();
      if (inByte == 'y') {
        EEPROM.put(eepromAdr, c);
        EEPROM.write(eepromAdrIsCalibrated, IS_CAL_VAL);
#if defined(ESP8266)
        EEPROM.commit();
#endif
        EEPROM.get(eepromAdr, c);
        Serial.print(F("Value "));
        Serial.print(c);
        Serial.print(F(" saved to EEPROM address: "));
        Serial.println(eepromAdr);
        _resume = true;
      }
      else if (inByte == 'n') {
        Serial.println(F("Value not saved to EEPROM"));
        _resume = true;
      }
    }
  }
#endif
  Serial.println(F("End change calibration value"));
  Serial.println(F("***"));
}


//*** calibrate battery voltage measurement:
void calibrateBatVoltage() {
  int analogreadval = 0;
  float voltage, calibrationval;
  boolean _resume = false;
  Serial.println(F("***"));
  Serial.println(F("Start calibration battery voltage (be sure that the battery is connected):"));
  Serial.print(F("Average analog read value from batRef_pin is:"));
  for (byte i = 0; i < 10; i++) {
    analogreadval += analogRead(batRef_pin);
    delay(10);
  }
  analogreadval /= 10;
  Serial.println(analogreadval);
  if ((analogreadval == 0) || (analogreadval == 1023)) {
    Serial.println(F("Analog read value is to high or to low, check your circuit, exit"));
    return;
  }
  Serial.println(F("Measure the voltage at the MCU VIN pin using a multimeter."));
  Serial.println(F("Send the result (i.e. 8.65) from the serial monitor."));
  while (_resume == false) {
    if (Serial.available() > 0) {
      voltage = Serial.parseFloat() * 1000;
      if (voltage != 0) {
        calibrationval = voltage / analogreadval;
        Serial.print(F("Calculated calibration value is: "));
        Serial.println(calibrationval);
        batvoltage_calfactor = calibrationval;
        _resume = true;
      }
      else {
        Serial.println(F("Invalid value, exit"));
        return;
      }
    }
  }

#ifdef USE_EEPROM
  Serial.print(F("Save this value to EEPROM adress "));
  Serial.print(ADR_BATVOLT_CAL);
  Serial.println(F("? y/n"));
  _resume = false;
  while (_resume == false) {
    if (Serial.available() > 0) {
      char inByte = Serial.read();
      if (inByte == 'y') {
        EEPROM.put(ADR_BATVOLT_CAL, calibrationval);
        EEPROM.write(ADR_BATVOLT_IS_CAL, IS_CAL_VAL);
#if defined(ESP8266)
        EEPROM.commit();
#endif
        EEPROM.get(ADR_BATVOLT_CAL, calibrationval);
        Serial.print(F("Value "));
        Serial.print(calibrationval);
        Serial.print(F(" saved to EEPROM address: "));
        Serial.println(ADR_BATVOLT_CAL);
        _resume = true;
      }
      else if (inByte == 'n') {
        Serial.println(F("Value not saved to EEPROM"));
        _resume = true;
      }
    }
  }
#endif
  Serial.println(F("End calibration voltage"));
  Serial.println(F("***"));
}


//*** handle zero offset button:
void zeroButton() {
#ifdef USE_ZERO_BUTTON
  static long lastSwTime = 0;
  static bool lastSwState = 1;
  const int debounceValue = 50;
  bool swstate = digitalRead(zero_button_pin);
  if (swstate != lastSwState) {
    if ((lastSwTime + debounceValue) < millis()) {
      if (swstate == HIGH) { //button was released
        delay(250);
        setZero();
      }
      lastSwState = swstate;
      lastSwTime = millis();
    }
  }
#endif
}


//*** flash power-on LED:
void flashLED() {
#ifdef USE_LED
  static long t = 0;
  static boolean ledState = 0;
  if (t < millis()) {
    if (ledState) {
      t = millis() + 2000;
      ledState = 0;
    }
    else {
      t = millis() + 100;
      ledState = 1;
    }
    digitalWrite(led_pin, ledState);
  }
#endif
}

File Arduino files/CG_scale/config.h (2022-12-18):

//** HX711 library configuration:
//** Number of samples and some filtering settings can be adjusted in the HX711_ADC.h library file
//** The best RATE setting is usually "LOW" 10SPS, see HX711 data sheet (RATE is selected by HX711 pin 15, this can be set by a solder jumper on some HX711 modules)
//** RATE "HIGH" 80SPS will also work, but conversions will be more noisy, so consider increasing number of samples in HX711_ADC.h

//** If you are setting up a new scale, please consider first testing the indivdual loadcells using the example file provided with the HX711 library, "Read_1x_load_cell.ino",
//** to ensure that direction of up/down force is working as it should. If not correct the loadcell wiring.



//** Uncomment one of the two lines below to enable either serial 16x2 character display or i2c 16x2 character display:
//#define USE_SERDISP
#define USE_I2CDISP

//** If using i2c display, set correct i2c address (if you don't know, use the i2c Scanner sketch: https://playground.arduino.cc/Main/I2cScanner/)
//** or you can even set the i2c address to 0x00 to let the hd44780 library auto locate the address
#define I2CDISP_ADR 0x00

//** Uncomment to enable optional EEPROM storing of loadcell calibration value (ldcell_1_calfactor and ldcell_2_calfactor):
#define USE_EEPROM

//** Uncomment if you want to connect an optional push button button to manually set zero offset
//#define USE_ZERO_BUTTON

//** Uncomment  if you want to connect an optional blinking LED for indicating power on (it's not very useful...)
//#define USE_LED

//** Set low battery voltage in units mV, battery voltage shown on the LCD will blink if voltage is below this value
const int lowBatVal = 6000;

//** Set the dimensional calibration values (see instruction sheet) in unit 1/10mm, measure using a calliper:
const long WingPegDist = 1200; //projected distance between wing support points
const long LEstopperDist = 300; //projected distance from front wing support point to leading edge (stopper pin)

//** Set loadcell calibration values (best to have the battery connected when doing calibration).
//** You can get the correct values by running the calibration routine and then insert the values in the sketch before re-uploading.
//** If you have enabled EEPROM (#define USE_EEPROM) the values below will be ignored once you have run the calibration routine and stored the values in EEPROM.
float ldcell_1_calfactor = 954.0; // calibration factor load cell front
float ldcell_2_calfactor = 799.0; // calibration factor load cell rear

//** LCD refresh interval ms
const int lcdprintInterval = 100;

//** serial monitor refresh interval ms
const int serialprintInterval = 500;

//** Battery voltage calibration:
//** The calibration value below comes from the VCC (5000mV), the analog resolution (1024) and the resistor divider circuit, like this:
//** ((5000*1000L)/1024) / ((R2/(R1+R2))*1000). This calibration value is multiplied with the analog read value to get the voltage in mV.
//** You can get the correct value by running the calibration routine and then insert the value in the sketch before re-upload.
//** If you have enabled EEPROM (#define USE_EEPROM) the value below will be ignored once you have run the calibration routine and stored the value in EEPROM.
float batvoltage_calfactor = 15.26;

//** Pin configuration for Arduino Pro-Mini and Arduino Nano:
//** If you use an i2c display, pin A4 is SDA and pin A5 is SCL for the display communication
//** If you use the Serial display, pin 1 for the display serial communication
//** Note that on the Atmega328 pin A6 and A7 is for analog read only.
const byte LoadCell_1_DOUT_pin = A2;    //HX711 DOUT pin for load cell front
const byte LoadCell_1_SCK_pin = A3;     //HX711 SCK pin for load cell front
const byte LoadCell_2_DOUT_pin = A0;    //HX711 DOUT pin for load cell rear
const byte LoadCell_2_SCK_pin = A1;     //HX711 SCK pin for load cell rear
const byte batRef_pin = A6;             //Battery voltage sense via resistor divider, range 0-5v (0-VCC)
const byte zero_button_pin = 5;         //optional zero offset push button
const byte led_pin = 3;                 //optional power-on blinking LED

//** Pin configuration for ESP8266, TODO!:
//const byte LoadCell_1_DOUT_pin = ;    //HX711 DOUT pin for load cell front
//const byte LoadCell_1_SCK_pin = ;     //HX711 SCK pin for load cell front
//const byte LoadCell_2_DOUT_pin = ;    //HX711 DOUT pin for load cell rear
//const byte LoadCell_2_SCK_pin = ;     //HX711 SCK pin for load cell rear
//const byte batRef_pin = A0;           //Battery voltage sense via resistor divider, range 0-1v
//const byte led_pin = ;                //optional power on blink LED
//const byte zero_button_pin = ;        //optional zero offset push button

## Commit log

2017-04-18 Rename CG_scale.ino to Arduino files/CG_scale.ino
2017-04-18 Rename SimpleSerialDisplay.ino to Arduino files/SimpleSerialDisplay.ino
2017-04-18 Rename License.txt to Arduino files/License.txt
2017-05-30 Update CG_scale.ino
    Simplifying code + fixed some bugs
    [CG_scale.ino]
2017-05-30 Update CG_scale.ino
    Simplified code + some bug fixing
    [CG_scale.ino]
2017-06-12 Add files via upload
    Corrected soft pad dia to 15mm
2017-06-30 Uploaded revised file
    It came to my attantion that there was an error in the previous LCD circuit diagram. This revised version should be correct.
2017-07-02 Add files via upload
    Larger support for F5J models
    [CG_scale_front_support_f5j-version.stl]
2017-07-06 Add files via upload
    Version for F5J gliders with higher and wider fuselage
    [CG_scale_rear_support_f5j-version.stl]
2017-10-16 Revised wiring
2018-01-05 added step file
    [CG_scale.stp]
2018-04-02 Add optional I²C-Display compatability
    There are many 16x2-Displays with a piggybagged I²C-Portexpander out
    there. These are easily supported by the LiquidCrystal_I2C-Library.
    This commit modifies the output field to be a byte instead of bool, and
    adds option output=2 for the I²C-Display. To include it, #define I2CDISP
    is also needed.
2018-04-02 Add documentation for I2C-Displays
2020-08-25 Added f5j stp
    [CG_scale_parts_f5j_3dprint.stp]
2020-10-14 Add big version
    [CG_scale_front_support_big-version.stl, CG_scale_rear_support_big-version.stl]
2020-10-16 Add step files for big version
    [CG_scale_front_support_big-version.step, CG_scale_rear_support_big-version.step]
2022-12-18 1.2.2
    Change i2c library
